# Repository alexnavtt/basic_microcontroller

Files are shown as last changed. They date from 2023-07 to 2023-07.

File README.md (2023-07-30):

# Basic Microcontroller

As the name suggests, this repo contains files and code an educational project of mine to build a microcontroller 
breakout board from scratch. I picked the ATMega32u4 for its native USB status, as well as for the wealth of tutorial
and educational material out there on the web. The board itself doesn't have much of a purpose, though anyone is free 
to use it as a reference for a similar project of their own. 

The board has the following features:
  * ATMega32u4 MCU running at 8 MHz
  * USB-C terminal
  * 6-pin ICSP header terminal
  * 1x ADC screw terminal
  * 1x I2C Stemma/QWIIC header
  * 1x RGB LED
  * 5x5 green LED array

There's no particular reason that I run the board at 8 MHz. Generally this MCU is operated at 16 MHz when operating a 
5VDC (which this board is). I just kinda picked 8 on a whim, and as a result I got an additional lesson in recompiling
Arduino bootloaders with modified settings, which I'm honestly really happy with. For an educational project, more things
to learn is always a good thing. Also, placing the LED array on the opposite side but at the same location as the MCU
forced me to get a little creative with wiring, and as my first 4-layer PCB I'm happy with the result 

I have no plans to update this board in the future, but I am thiniking of doing a similar project which an ARM MCU, probably
something simple like an ESP32. We'll see where I end up.

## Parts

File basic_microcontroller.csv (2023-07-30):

# | Reference | Qty | Value | Footprint | DNP
1 | C1, C2 | 2 | 20pF | Capacitor_SMD:C_0603_1608Metric_Pad1.08x0.95mm_HandSolder
2 | C3 | 1 | 1uF | Capacitor_SMD:C_0603_1608Metric_Pad1.08x0.95mm_HandSolder
3 | C4, C5, C7, C8 | 4 | 100nF | Capacitor_SMD:C_0603_1608Metric_Pad1.08x0.95mm_HandSolder
4 | C6 | 1 | Stemma | basic_microcontroller:stemma
5 | D1, D2, D3, D4, D5, D6, D7, D8, D9, D10, D11, D12, D13, D14, D15, D16, D17, D18, D19, D20, D21, D22, D23, D24, D25, D26, D28 | 27 | LED | LED_SMD:LED_0805_2012Metric_Pad1.15x1.40mm_HandSolder
6 | D27 | 1 | LED_ABRG | basic_microcontroller:RGB LED
7 | F1 | 1 | Polyfuse | Fuse:Fuse_1206_3216Metric_Pad1.42x1.75mm_HandSolder
8 | J1 | 1 | USB_C_Receptacle_USB2.0 | basic_microcontroller:USB480003A
9 | J2 | 1 | AVR-ISP-6 | Connector_IDC:IDC-Header_2x03_P2.54mm_Vertical
10 | J3 | 1 | Screw_Terminal_01x02 | TerminalBlock_Phoenix:TerminalBlock_Phoenix_MPT-0,5-2-2.54_1x02_P2.54mm_Horizontal
11 | R1, R2 | 2 | 22 | Resistor_SMD:R_0805_2012Metric_Pad1.20x1.40mm_HandSolder
12 | R3, R5, R6 | 3 | 5.1k | Resistor_SMD:R_0603_1608Metric_Pad0.98x0.95mm_HandSolder
13 | R4 | 1 | 1M | Resistor_SMD:R_0805_2012Metric_Pad1.20x1.40mm_HandSolder
14 | R7, R8, R9, R10, R11, R12, R13, R14, R15, R16, R17, R18, R19, R20, R21, R22, R23, R24, R25, R26, R27, R28, R29, R30, R31, R32, R33, R38 | 28 | 140 | Resistor_SMD:R_0805_2012Metric_Pad1.20x1.40mm_HandSolder
15 | R34, R35 | 2 | 91 | Resistor_SMD:R_0805_2012Metric_Pad1.20x1.40mm_HandSolder
16 | R36, R37 | 2 | 10k | Resistor_SMD:R_0805_2012Metric_Pad1.20x1.40mm_HandSolder
17 | S1 | 1 | Pushbutton Switch | basic_microcontroller:Pushbutton Switch
18 | U1 | 1 | ATmega32U4-A | Package_QFP:TQFP-44_10x10mm_P0.8mm
19 | Y1 | 1 | 8MHz | basic_microcontroller:ECS80185PXGMTR

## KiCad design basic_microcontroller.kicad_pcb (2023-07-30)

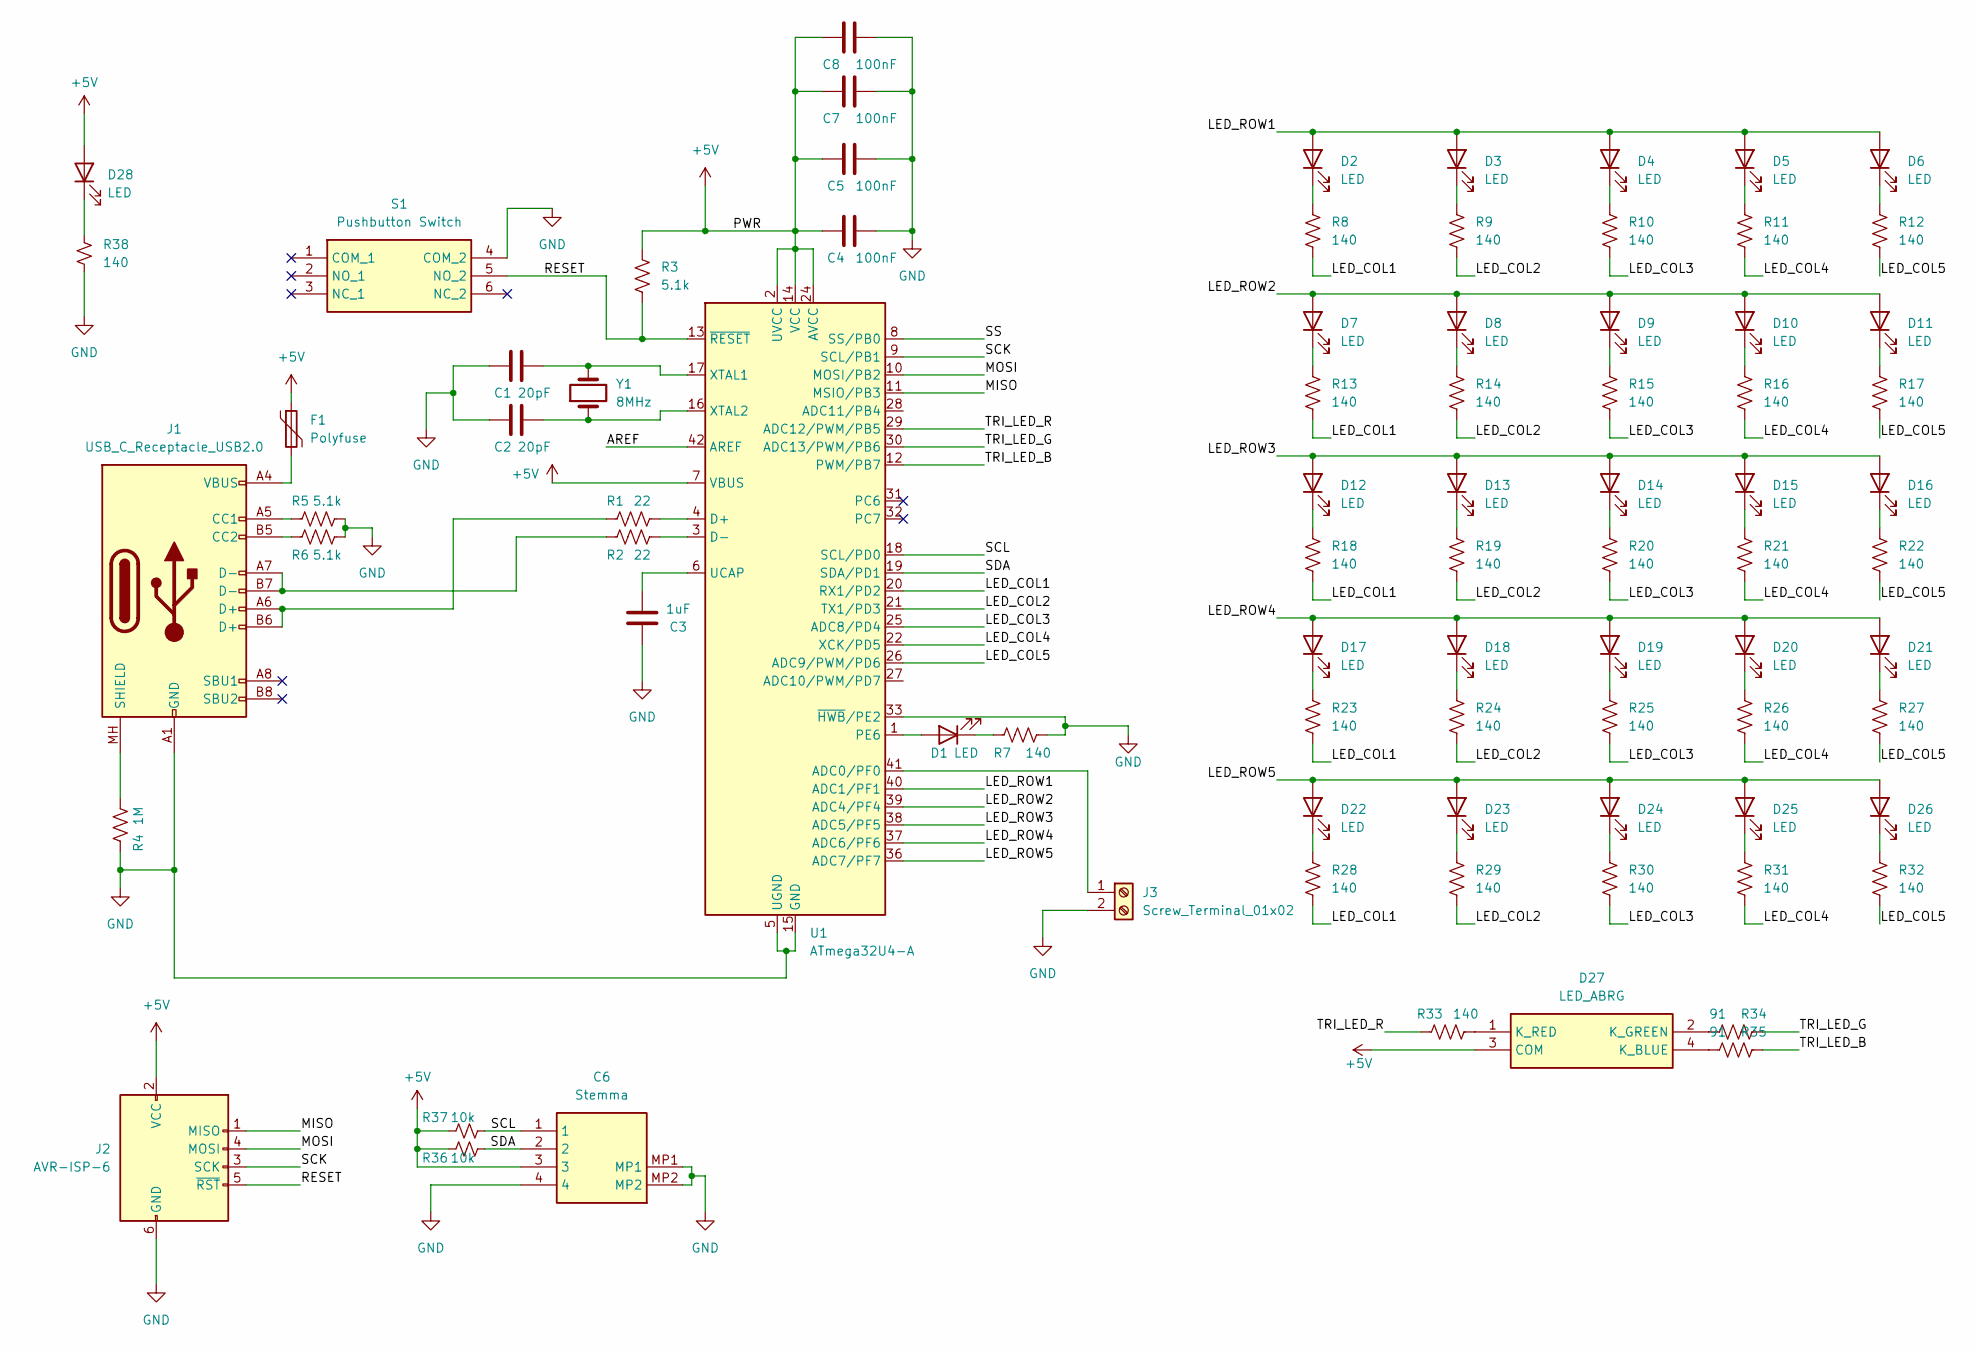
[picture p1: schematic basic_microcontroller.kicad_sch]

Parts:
C1, C2: 20pF; C_0603_1608Metric_Pad1.08x0.95mm_HandSolder
C3: 1uF; C_0603_1608Metric_Pad1.08x0.95mm_HandSolder
C4, C5, C7, C8: 100nF; C_0603_1608Metric_Pad1.08x0.95mm_HandSolder
C6: Stemma; stemma; Mouser Part Number 485-4392
D1, D2, D3, D4, D5, D6, D7, D8, D9, D10, D11, D12, D13, D14, D15, D16, D17, D18, D19, D20, D21, D22, D23, D24, D25, D26, D28: LED; LED_0805_2012Metric_Pad1.15x1.40mm_HandSolder
D27: LED_ABRG; RGB LED; Mouser Part Number 743-IN-S85TATRGB
F1: Polyfuse; Fuse_1206_3216Metric_Pad1.42x1.75mm_HandSolder
J1: USB_C_Receptacle_USB2.0; USB480003A
J2: AVR-ISP-6; IDC-Header_2x03_P2.54mm_Vertical
J3: Screw_Terminal_01x02; TerminalBlock_Phoenix_MPT-0,5-2-2.54_1x02_P2.54mm_Horizontal
R1, R2: 22; R_0805_2012Metric_Pad1.20x1.40mm_HandSolder
R3, R5, R6: 5.1k; R_0603_1608Metric_Pad0.98x0.95mm_HandSolder
R4: 1M; R_0805_2012Metric_Pad1.20x1.40mm_HandSolder
R7, R8, R9, R10, R11, R12, R13, R14, R15, R16, R17, R18, R19, R20, R21, R22, R23, R24, R25, R26, R27, R28, R29, R30, R31, R32, R33, R38: 140; R_0805_2012Metric_Pad1.20x1.40mm_HandSolder
R34, R35: 91; R_0805_2012Metric_Pad1.20x1.40mm_HandSolder
R36, R37: 10k; R_0805_2012Metric_Pad1.20x1.40mm_HandSolder
S1: Pushbutton Switch; Mouser Part Number 688-SPEJ110100
U1: ATmega32U4-A; TQFP-44_10x10mm_P0.8mm
Y1: 8MHz; ECS80185PXGMTR

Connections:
+5V: C4.2, C5.2, C6.3, C7.2, C8.2, D27.3 (COM), D28.2 (A), F1.1, J2.2 (VCC), R3.1, R36.1, R37.1, U1.2 (UVCC), U1.7 (VBUS), U1.14 (VCC), U1.24 (AVCC), U1.34 (VCC), U1.44 (AVCC)
/AREF: U1.42 (AREF)
/LED_COL1: R8.2, R13.2, R18.2, R23.2, R28.2, U1.20 (RX1/PD2)
/LED_COL2: R9.2, R14.2, R19.2, R24.2, R29.2, U1.21 (TX1/PD3)
/LED_COL3: R10.2, R15.2, R20.2, R25.2, R30.2, U1.25 (ADC8/PD4)
/LED_COL4: R11.2, R16.2, R21.2, R26.2, R31.2, U1.22 (XCK/PD5)
/LED_COL5: R12.2, R17.2, R22.2, R27.2, R32.2, U1.26 (ADC9/PWM/PD6)
/LED_ROW1: D2.2 (A), D3.2 (A), D4.2 (A), D5.2 (A), D6.2 (A), U1.40 (ADC1/PF1)
/LED_ROW2: D7.2 (A), D8.2 (A), D9.2 (A), D10.2 (A), D11.2 (A), U1.39 (ADC4/PF4)
/LED_ROW3: D12.2 (A), D13.2 (A), D14.2 (A), D15.2 (A), D16.2 (A), U1.38 (ADC5/PF5)
/LED_ROW4: D17.2 (A), D18.2 (A), D19.2 (A), D20.2 (A), D21.2 (A), U1.37 (ADC6/PF6)
/LED_ROW5: D22.2 (A), D23.2 (A), D24.2 (A), D25.2 (A), D26.2 (A), U1.36 (ADC7/PF7)
/MISO: J2.1 (MISO), U1.11 (MSIO/PB3)
/MOSI: J2.4 (MOSI), U1.10 (MOSI/PB2)
/RESET: J2.5 (~RST), R3.2, S1.5 (NO_2), U1.13 (~RESET)
/SCK: J2.3 (SCK), U1.9 (SCL/PB1)
/SCL: C6.1, R37.2, U1.18 (SCL/PD0)
/SDA: C6.2, R36.2, U1.19 (SDA/PD1)
/SS: U1.8 (SS/PB0)
/TRI_LED_B: R35.1, U1.12 (PWM/PB7)
/TRI_LED_G: R34.1, U1.30 (ADC13/PWM/PB6)
/TRI_LED_R: R33.1, U1.29 (ADC12/PWM/PB5)
GND: C1.1, C2.1, C3.1, C4.1, C5.1, C6.4, C6.MP1, C6.MP2, C7.1, C8.1, J1.A1 (GND), J1.A12 (GND), J1.B1 (GND), J1.B12 (GND), J2.6 (GND), J3.2, R4.1, R5.2, R6.2, R7.2, R38.2, S1.4 (COM_2), U1.5 (UGND), U1.15 (GND), U1.23 (GND), U1.33 (~HWB/PE2), U1.35 (GND), U1.43 (GND)
unnamed: D1.2 (A), U1.1 (PE6)
unnamed: D1.1 (K), R7.1
unnamed: D2.1 (K), R8.1
unnamed: D3.1 (K), R9.1
unnamed: D4.1 (K), R10.1
unnamed: D5.1 (K), R11.1
unnamed: D6.1 (K), R12.1
unnamed: D7.1 (K), R13.1
unnamed: D8.1 (K), R14.1
unnamed: D9.1 (K), R15.1
unnamed: D10.1 (K), R16.1
unnamed: D11.1 (K), R17.1
unnamed: D12.1 (K), R18.1
unnamed: D13.1 (K), R19.1
unnamed: D14.1 (K), R20.1
unnamed: D15.1 (K), R21.1
unnamed: D16.1 (K), R22.1
unnamed: D17.1 (K), R23.1
unnamed: D18.1 (K), R24.1
unnamed: D19.1 (K), R25.1
unnamed: D20.1 (K), R26.1
unnamed: D21.1 (K), R27.1
unnamed: D22.1 (K), R28.1
unnamed: D23.1 (K), R29.1
unnamed: D24.1 (K), R30.1
unnamed: D25.1 (K), R31.1
unnamed: D26.1 (K), R32.1
unnamed: D27.4 (K_BLUE), R35.2
unnamed: D27.2 (K_GREEN), R34.2
unnamed: D27.1 (K_RED), R33.2
unnamed: D28.1 (K), R38.1
unnamed: F1.2, J1.A4 (VBUS), J1.A9 (VBUS), J1.B4 (VBUS), J1.B9 (VBUS)
unnamed: J1.A5 (CC1), R5.1
unnamed: J1.B5 (CC2), R6.1
unnamed: J1.A6 (D+), J1.B6 (D+), R1.1
unnamed: J1.A7 (D-), J1.B7 (D-), R2.1
unnamed: J1.MH (SHIELD), R4.2
unnamed: J3.1, U1.41 (ADC0/PF0)
unnamed: R1.2, U1.4 (D+)
unnamed: R2.2, U1.3 (D-)
unnamed: C3.2, U1.6 (UCAP)
unnamed: C1.2, U1.17 (XTAL1), Y1.2
unnamed: C2.2, U1.16 (XTAL2), Y1.1

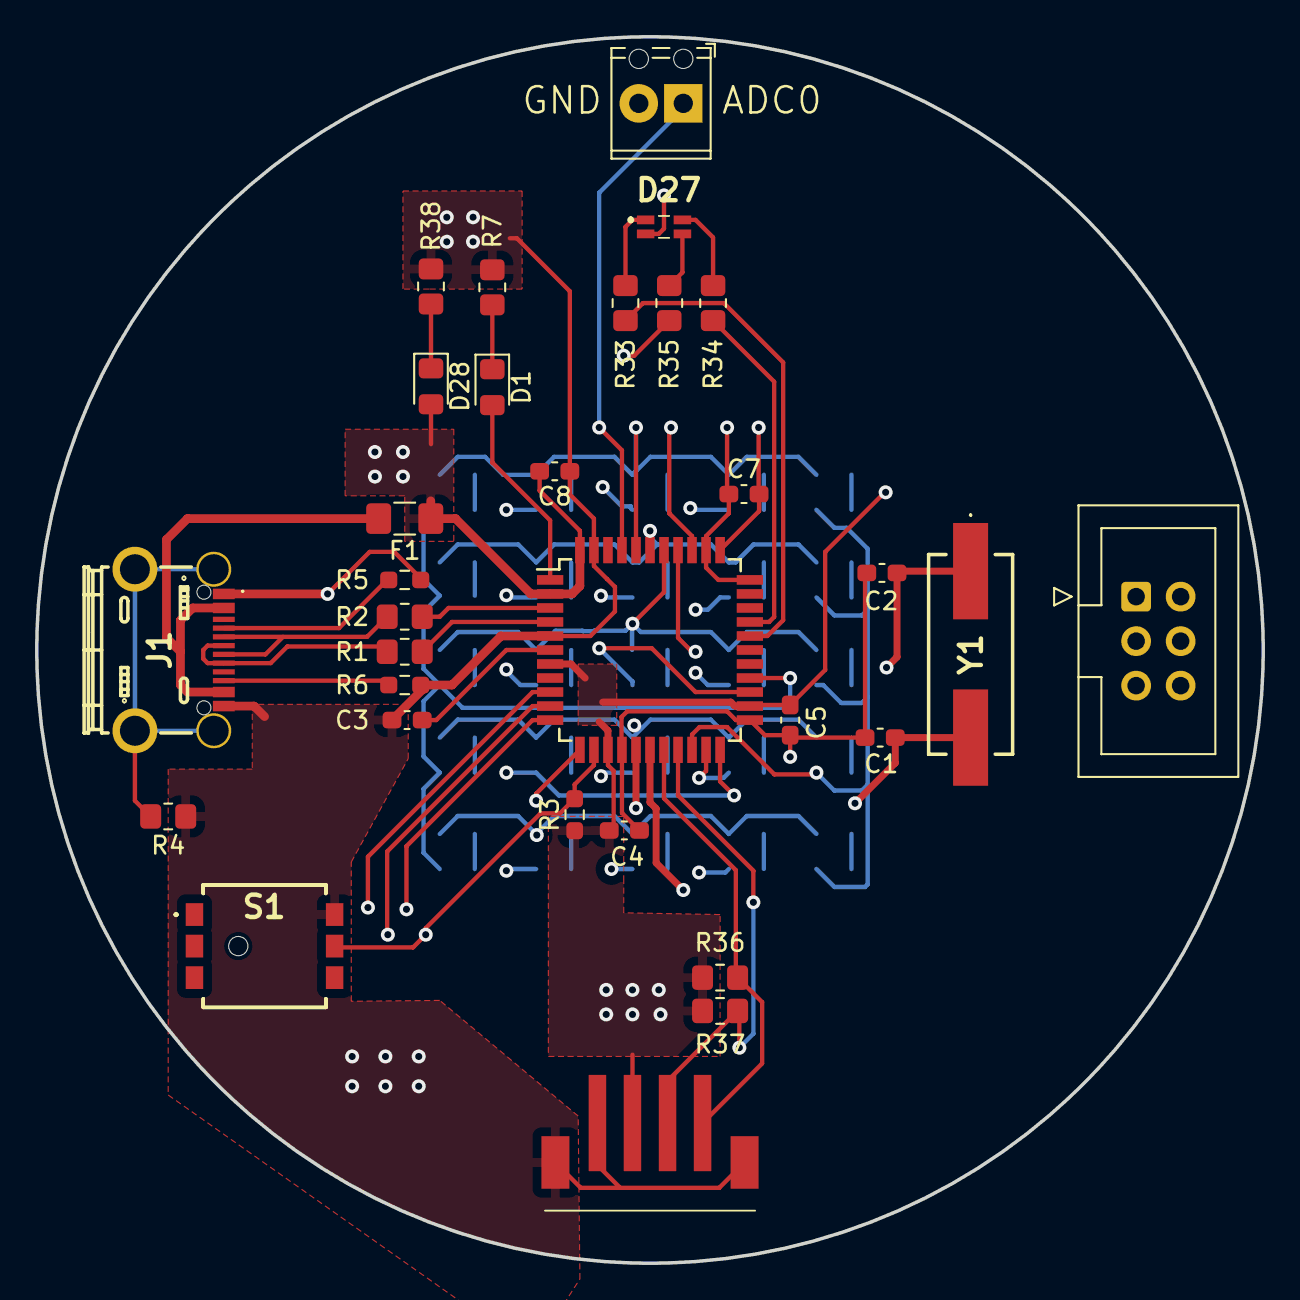
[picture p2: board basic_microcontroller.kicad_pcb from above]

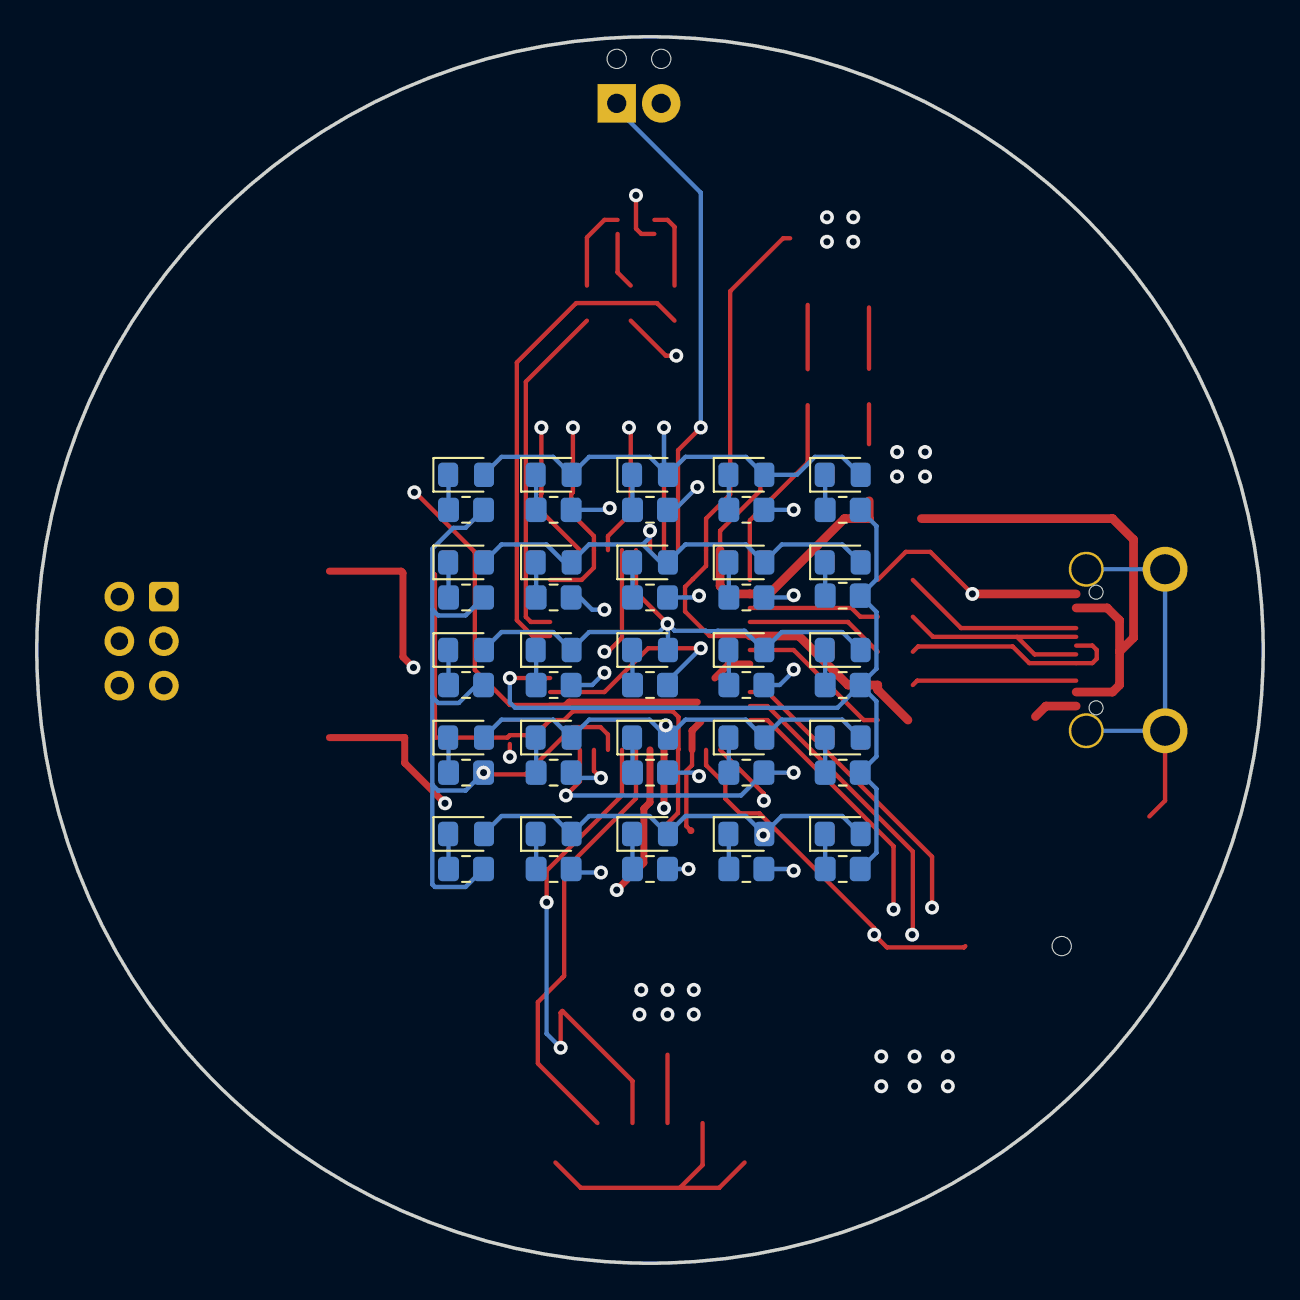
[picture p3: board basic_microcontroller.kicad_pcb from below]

Board: 4 copper layers, 70.0 x 70.0 mm, 81 parts (50 on the bottom side), 64 nets.

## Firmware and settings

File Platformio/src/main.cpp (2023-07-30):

#include <Arduino.h>

#include "Message.h"
#include "Characters.h"

static Message message;

void setup(){
    using namespace characters;

    message.init();
    message.addImage(H);
    message.addImage(I);
    message.addImage(R);
    message.addImage(E);
    message.addImage(SPACE);
    message.addImage(M);
    message.addImage(E);
    message.addImage(EXCLAMATION);
}

void loop(){
    message.playMessage(500, true, true);
    delay(1000);
}
